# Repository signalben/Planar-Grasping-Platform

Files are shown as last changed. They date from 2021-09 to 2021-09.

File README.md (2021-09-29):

# Planar-Grasping-Platform

<p float="left">
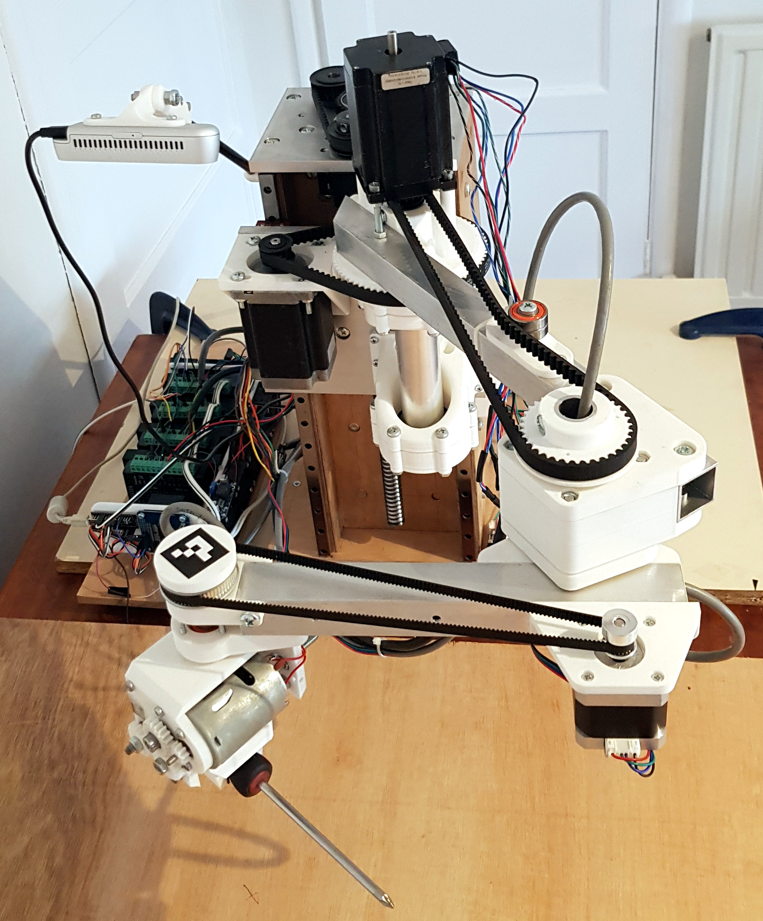
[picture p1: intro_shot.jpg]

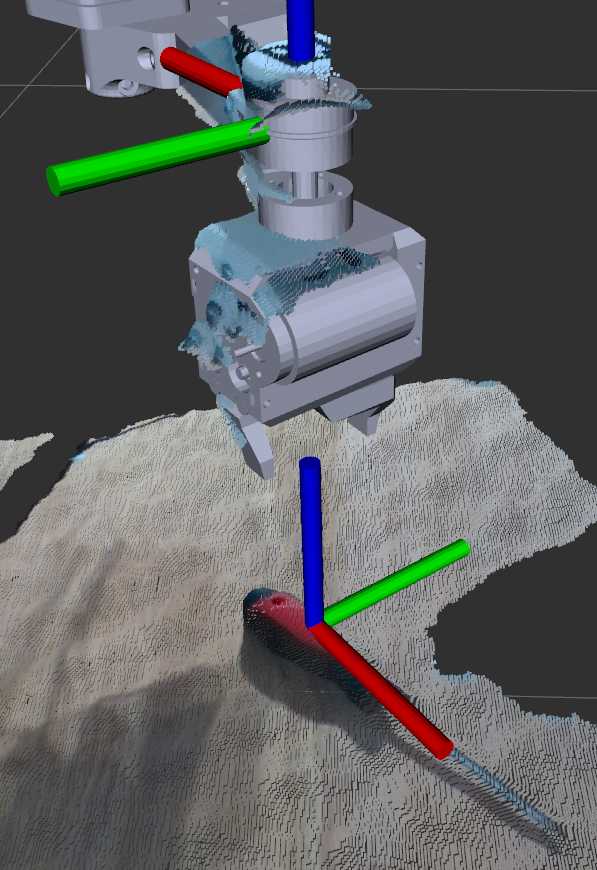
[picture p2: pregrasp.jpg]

</p>

_________________________________________________________________________________
## Demonstration videos

Successful grasps:  
https://youtu.be/Sxl_OcmL-3o  
https://youtu.be/Iijbrh8ghpE  
https://youtu.be/rKQw1soyyW4  

Failed grasps:  
https://youtu.be/VdM2XRzhyX0  
https://youtu.be/__iQ3P3LJT0  
https://youtu.be/dziLtvFLTpc  

Visualizations:  
https://youtu.be/MQvtPGrG9rY  
https://youtu.be/M_flOcwguvU

_________________________________________________________________________________
## Components
scara_CAD 		- Contains models of the scara arm, gripper, mounts for the endstops, camera, microcontrollers  
Arduino_controllers	- Contains the Arduino sketches used for low-level control of the scara arm and gripper  
electrical_schematic	- Details electrical components used and is a full wiring diagram  
scara_ws		- Is the ROS workspace used for high-level control of the arm  
grasp_generation	- Is the implimentation used for generating planar grasps from depth images  
_________________________________________________________________________________
## Prerequisites
Ubuntu   version: 16.04  
ROS    	 version: kinetic
_________________________________________________________________________________
## Running in demo mode
This repository is already configured to run without a physical robot.
However, an Arduino Mega and an Arduino Nano are required.

For use with a real robot, set real_robot = true in the following files:
Arduino_controllers/gripper/gripper.ino  
scara_ws/src/scara_grasping/scripts/execute_grasps.py  
_________________________________________________________________________________
## Setup

Please refer to the installation instructions in the following files:

/Arduino_controllers/README  
/scara_ws/src/README  
/grasp_generation/ggcnn-master/README  
_________________________________________________________________________________
## Running Manipulator
-after Arduino, ROS, CNN installations, connect Nano to "/dev/ttyUSB0"  
-port is specified in ~/scara_ws/src/scara_driver/src/driver.cpp  

-In a new terminal:  
roscore  

-In a new terminal:  
rosrun scara_driver driver  

-In a new terminal:  
rosrun scara_driver user  

-In a new terminal:  
rostopic echo /update/joint_states  

-In the user terminal:  
&E  
-the driver terminal should now print "Enabled control of arm and gripper"    

-In the user terminal:  
 #?  
-the driver terminal prints the status of GRBL  
-this begins with "<alarm|" , indicating that the arm has not been homed and is disabled for safety  
-the /update/joint_states topic should echo one new jointstate, as reported by GRBL status message  

-Either disable the homing requirement by entering in the user terminal:  
 #$X  

-Or home a real manipulator to endstops by instead entering:  
 #$H  

-In the user terminal:  
 #?  
-The GRBL status message should now begin with <Idle|  
-the /update/joint_states topic should echo another jointstate  
 
-In the user terminal:  
run  

-The driver terminal reports "Updating Jointstates from GRBL.."  
-the /update/joint_states topic continuously updates at 10hz  
-the driver node no longer shows status messages  
-updating the jointstates can be disabled by entering 'stop' in the user node  

-In a new terminal:  
rosrun scara_grasping joint_trajectory_action.py  

-In a new terminal:  
roslaunch scara_bringup bringup.launch  
  - If no camera is plugged in, use realsense:=0 argument not to run the camera node   
  - To disable the broadcast of a static transform for the camera use argument camera_pose:=0  

-RVIZ should open, with the scara manipulator and a motionplanning panel shown on screen  
__________________________________________________________________________________
## Veryifying setup

To verify:  
- In the 'MotionPlanning' panel, select 'Planning' -> 'Select Goal State' -> 'ready'  
- Then click 'Update', then 'Plan and Execute'  
- The model should move from the home position to a new pose, it's position is fedback by GRBL  

The arm can also be commanded manually using G-CODE in the user terminal, eg:  
#G0 X-30   (moves XJ 30 deg clockwise)  
&C150      (sets jaw opening width)  
_________________________________________________________________________________
## Grasping  

-In a new terminal:  
roslaunch scara_grasping cnn.launch  

To run the grasping routine-  
In a new terminal:  
rosrun scara_grasping execute_grasps.py  

To only view grasps-  
Close execute_grasps.py, in a new terminal:   
rosrun scara_grasping view_grasps.py  

-The calibration routine will not work without a real robot  
To run the calibration routine for determining the camera pose:    
Close execute_grasps.py, view_grasps.py, bringup.launch   

in a new terminal:   
roslaunch scara_bringup bringup.launch camera_pose:=0   

in a new terminal:  
rosrun scara_grasping calibration.py  
__________________________________________________________________________________
## Debugging    
Should an unresolvable error occur, restart all terminals and roscore.  
This won't lose the manipulators position, the setup commands are listed again below:  

roscore  
rosrun scara_driver driver  
rosrun scara_driver user  
 &E  
 #$X  
 run  
rosrun scara_grasping joint_trajectory_action.py  
roslaunch scara_bringup bringup.launch   

Common errors:  
0 grasps detected   		- Is the RGB-D camera pointed at an object?  
Gripper not in view 		- Is an AruCo marker fully visible in /camera/color/image_rect_color?  
Failed to get grasp from CNN    - roslaunch scara_grasping cnn.launch  

__________________________________________________________________________________

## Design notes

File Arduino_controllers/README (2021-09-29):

This software allows low-level actuation of the scara arm and gripper, controlled over USB serial. 

The gripper controller was developed as part of this work, but includes code references. It runs on an Arduino Nano.
The scara controller is existing software. It runs on an Arduino Mega 2560.

_________________________________________________________________________________
## Installation

Plug in an Arduino Mega, open the Arduino IDE, select tools -> board -> Mega 2560
From the top bar select Sketch -> Include Library -> Add ZIP.library
Navigate to the following folder, click OK:
~/Arduino_controllers/scara_controller/grbl-Mega-4axis-4axis/grbl
Open and upload the sketch:
~/Arduino_controllers/scara_controller/grbl-Mega-4axis-4axis/grbl/examples/grblUpload/grblUpload.ino
To verify the upload, on the serial monitor at 57600 baud, the following message should be recieved:
"Grbl 1.1e ['$' for help]"

Plug in an Arduino Nano, in the Arduino IDE, select tools -> board -> Nano
Open and upload the sketch:
~/Arduino_controllers/gripper/gripper.ino
To verify the upload, on the serial monitor at 57600 baud, the following message should be recieved:
"Ready - Use &E to enable control"

Using jumper leads, link the following pins:
Mega Rx0 to Nano D9
Mega Rx1 to Nano D8 
Mega Gnd to Nano Gnd

For further use only the Nano should be connected via USB

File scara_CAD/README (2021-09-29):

These folders contain the deign for all the mechanical components of the grasping platform.
The Solidworks parts and assemblies are present, but not the STLs used to 3D print them.

The main manipulator with gripper assembly is: 
manipulator/arm.SLDASM

The gripper and camera mounts are the following subassemblies:
gripper/gripper.SLDASM
realsenseD415_mount/realsense_mount.SLDASM

Designs produced to mount the endstop switches, electronics, and to test the grippers force are also included:
/home/ben/Planar-Grasping-Platform/scara_CAD/endstops
/home/ben/Planar-Grasping-Platform/scara_CAD/controller
/home/ben/Planar-Grasping-Platform/scara_CAD/force_sensor_package/load_cell_cone.SLDPRT

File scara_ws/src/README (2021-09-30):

__________________________________________________________________________
## Overview

scara_ws contains packages, folders for operation of the SCARA manipulator and gripper:

serial              - folder contains C++ library to allow USB serial port comms 
scara_driver        - allows ROS control over serial
scara_description   - folder contains URDF and STLs of mechanical design
scara_moveit_config - configuration for control of arm with moveit  
scara_bringup       - runs static camera transform, joint state publisher, robot state publisher, realsense camera, moveit, rviz
scara_grasping      - controller for moveit to control arm. Starts the CNN. Provides routines for grasp execution, grasp visualization and calibration of camera pose

Please note the naming convention of manipulator joints, where:  
J1 = ZJ, J2 = XJ, J3 = YJ, J4 = AJ

References:
Serial library
Website: http://wjwwood.github.io/serial/

All other packages and folders were developed as part of this work, but depend on referenced existing work and code
__________________________________________________________________________
## Installation of ROS

Used following guide to install ROS kinetic:
http://wiki.ros.org/kinetic/Installation/Ubuntu 

This specific installation used: 
sudo apt-get install ros-kinetic-desktop-full
echo "source /opt/ros/kinetic/setup.bash" >> ~/.bashrc
source ~/.bashrc
sudo apt install python-rosdep python-rosinstall python-rosinstall-generator python-wstool build-essential
sudo rosdep init
rosdep update
_________________________________________________________________________________
## Installation of ROS packages

-In a new terminal:
cd Planar-Grasping-Platform/scara_ws/
catkin_make

-Add the fullpath of scara_ws/devel/setup.bash to bashrc:
echo "source /home/"YOUR_USERNAME"/Planar-Grasping-Platform/scara_ws/devel/setup.bash" >> ~/.bashrc
source ~/.bashrc

-In a new terminal:
roscd scara_description
python localize.py

-Install prerequisite packages:

sudo apt-get install ros-kinetic-realsense2-camera
sudo apt install ros-kinetic-rgbd-launch
sudo apt-get install ros-kinetic-moveit

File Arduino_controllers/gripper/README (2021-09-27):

gripper.ino is designed for use on a Arduino Nano.

It has 4 main purposes:
	1-Pass serial communication recieved on port0 (PC) to port1 (Arduino Mega running GRBl)
	2-Pass feedback from GRBl to PC
	3-Control the gripper as specified by PC
	4-Pass feedback from the gripper to PC

Since the Nano has only one hardware serial port, AltSoftSerial is used for port1.

The main loop simply checks port0 and port1 for incoming mesages. Messages from GRBL are forwarded to the PC.
Messages from the PC are either passed to GRBL, or interpreted as a gripper command (depnding on prefix # or &) 
Gripper commands may (depending on prefixes C,D,L,H,S,P)
	E -enable communication with the gripper and arm
	C -control the gripper using PID to a specified position
	D -disable communication with the gripper and arm
	L -report the minimum safe sensor value
	H -report the maximum safe sensor value
	S -report the current sensor value
	P -close the gripper using a constant PWM value

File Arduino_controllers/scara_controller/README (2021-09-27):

GRBL is used for low-level control of the scara arm by an Arduino Mega.
This existing software has not been modified, other than setting configuration parameters

To flash GRBL onto an Arduino Mega2560:
	-in the Arduino IDE, open grbl-Mega-4axis-4axis/grbl/examples/grblUpload.ino
	-compile & upload only grblUpload.ino, it pulls in everything else

Reference:

	https://github.com/dguerizec/grbl-Mega-4axis

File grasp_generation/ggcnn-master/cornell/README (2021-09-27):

The Cornell grasping dataset is over 11gb, so it is not included here.

The original link for downloading the Cornell grasping dataset is dead, but it can be downloaded from:
	https://www.kaggle.com/oneoneliu/cornell-grasp

After downloading, extract into this folder, giving this structure:
	Planar-Grasping-Platform/grasp_generation/ggcnn-master/cornell/samples

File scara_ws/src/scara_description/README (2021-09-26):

The scara description package contains:

-STl files for each link of the scara arm and gripper

-The URDF describing the kinematics scara arm and gripper
	Upon this URDF moveit depends for control of the arm and RVIZ depends for visualization of the STL files.
	The URDF was automatically created by the SolidWorks to URDF Exporter- Originally created by Stephen Brawner (brawner@gmail.com), http://wiki.ros.org/sw_urdf_exporter

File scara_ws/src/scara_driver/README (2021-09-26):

The scara driver package provides an interface between ROS and the controllers for the manipulator and gripper.

The driver node requires a device connected to /dev/ttyUSB0 to run, and will not tolerate disconnection of the device whilst running.
However, the positions of the arm are stored by GRBL, so the driver node may be restarted without losing the position of the arm.

The user node is primarily for debugging/inspection of the microcontrollers via serial.
However, it is required to manually enable and home the arm on startup with '&E' and '#$H'

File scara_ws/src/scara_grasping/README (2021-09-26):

In /scripts, the scara_grasping package provides high-level functionality for:
	executing grasps
	viewing grasps
	calibrating the cameras frame relative to the world

These functionalities depend on scripts in scripts/utils, which provide:
	a link via sockets to the CNN, which also captures depth images (cnn_link.py)
	a controller for MoveIt (joint_trajectory_action.py)
	helper classes for control of the gripper (move_gripper.py)
	helper classes for control using MoveIt (move_group.py)
	helper classes for tf functions (projection.py)
	helper classes for obtaining the grippers position visually, which also captures RGB images (visual_feedback.py)

cnn.launch uses a bash script to start the CNN for generating grasps

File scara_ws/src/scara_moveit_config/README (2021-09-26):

This package contains the configuration and launch files required to control the SCARA arm with the moveit package.
-Do not run/launch any files in this package directly, they are called from scara_bringup bringup.launch.

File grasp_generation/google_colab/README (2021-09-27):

The file lists the Jupiter Cell commands used within Google Colab to train the GGCNN and derivatives of it remotely
Upload is much quicker without orginal .pcd files from Cornell dataset,
Once .tiffs are produced by ggcnn-master/utils/dataset_processing/generate_cornell_depth.py, GGCNN training only uses the much smaller .tiffs

#check that GPU is assigned
	!nvidia-smi

#mount google drive as persistant storage (prompts browser login)
	from google.colab import drive
	drive.mount('/content/gdrive')

#navigate to /root of runtime instance machine
	cd

#make folder for temporary storage local to runtime instance 
	mkdir /content/ggcnn-master

#copy entire dataset, everything else needed for training to runtime instance
#make take 1hr+    
	!cp -r "/content/gdrive/My Drive/ggcnn-master" "/content/ggcnn-master"

#navigate train_ggcnn.py directory
	cd /content/ggcnn-master/ggcnn-master/

#begin training 
#use run after (ctrl F10), so that following commands are executed automatically
#1 epoch = around 4 mins on Tesla V100
	!python3 train_ggcnn.py --description test10 --network ggcnn2 --dataset cornell --dataset-path "cornell" --epochs 100

#navigate to /root
	cd

#copy trained model to google drive
!cp -r "/content/ggcnn-master/ggcnn-master/output" "/content/gdrive/My Drive"

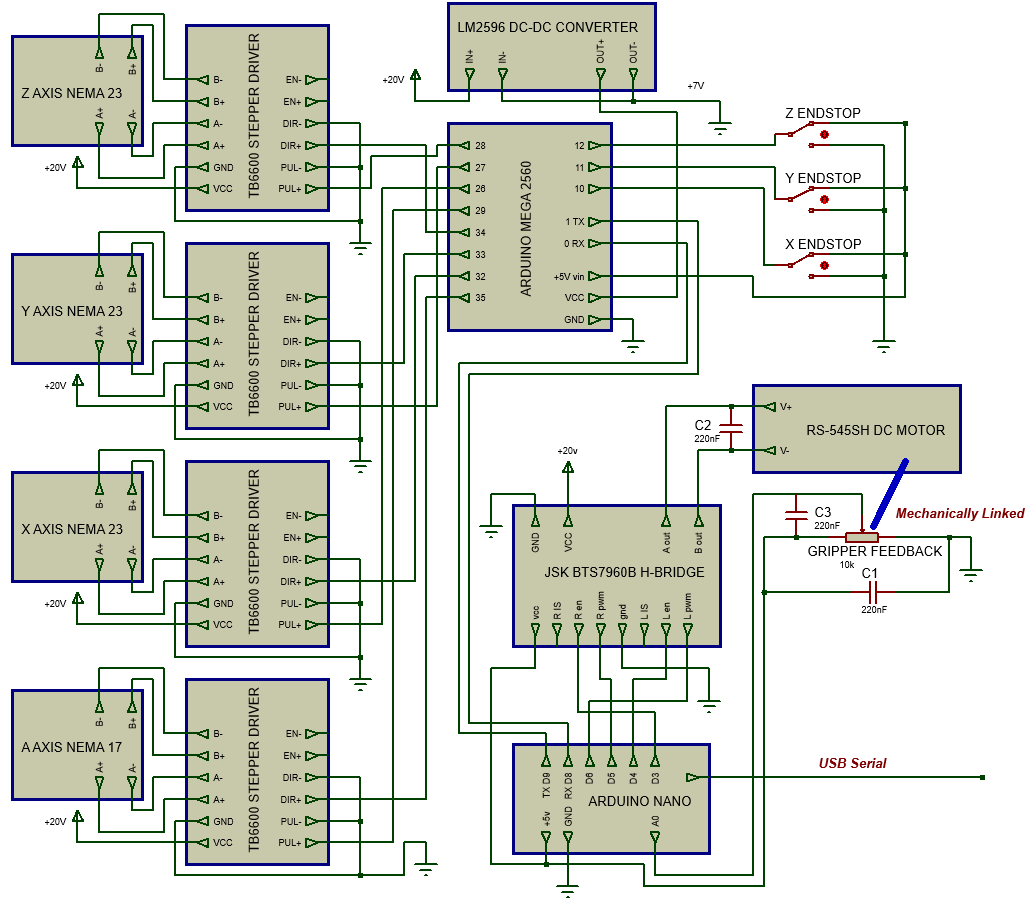
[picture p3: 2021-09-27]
electrical_schematic.png

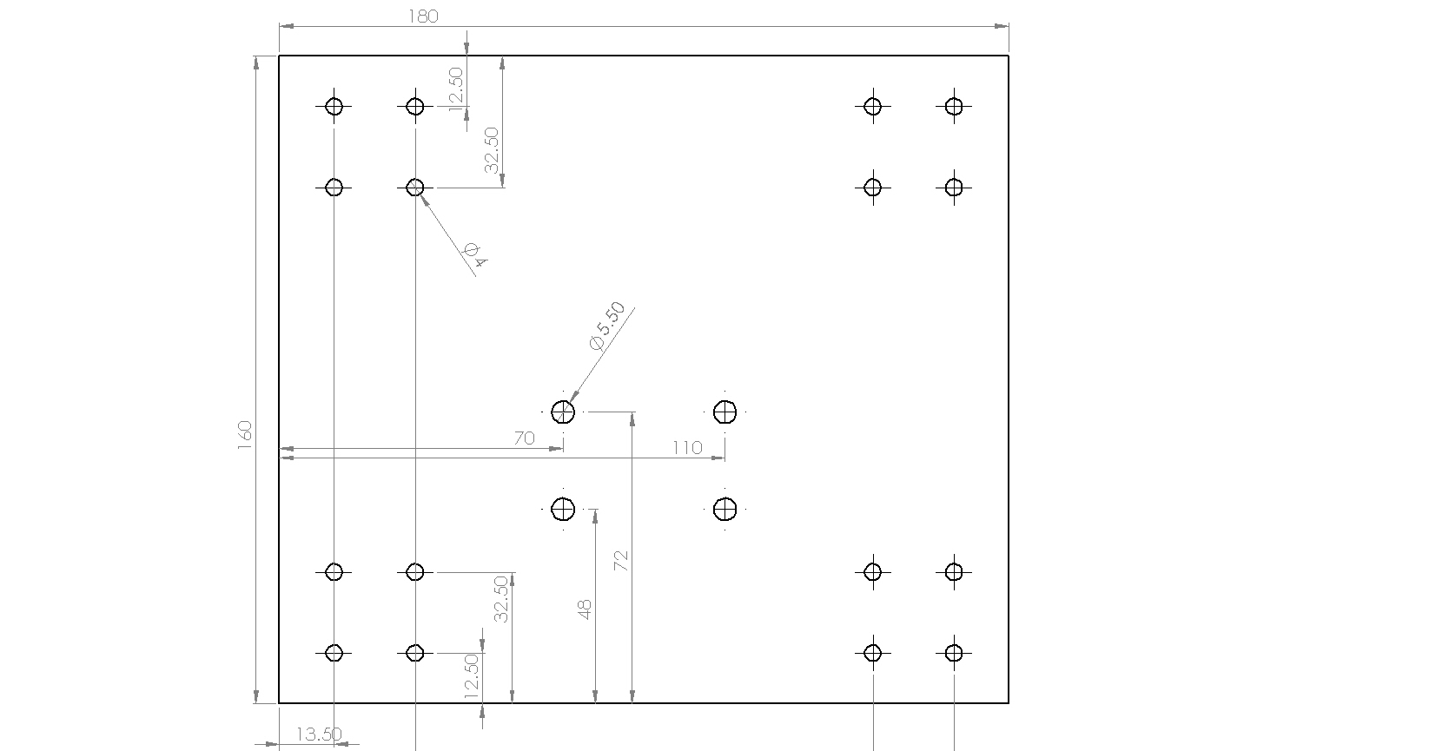
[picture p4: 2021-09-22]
scara_CAD/plate_drawings/mount_plate.JPG

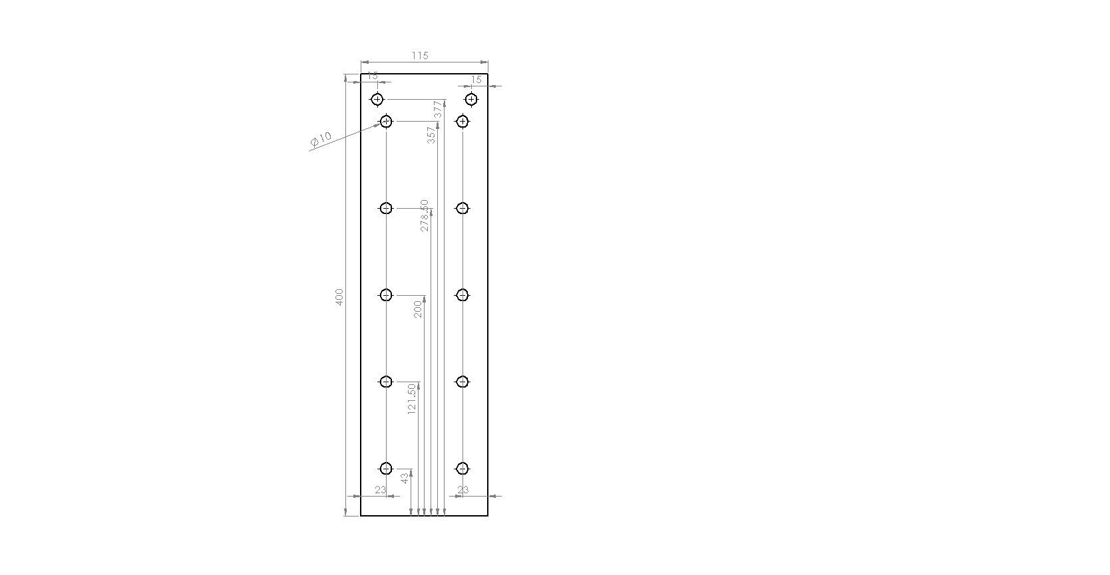
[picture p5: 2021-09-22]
scara_CAD/plate_drawings/back_plate.JPG

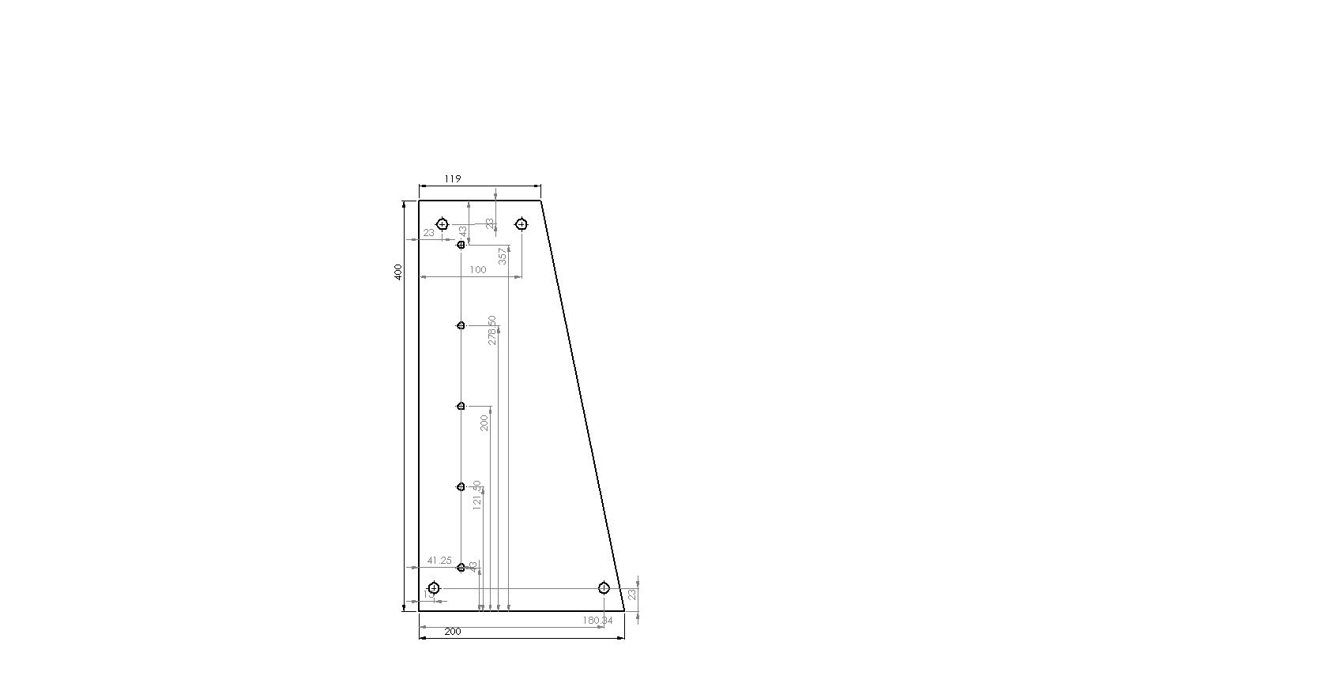
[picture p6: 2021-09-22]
scara_CAD/plate_drawings/side_plate.JPG

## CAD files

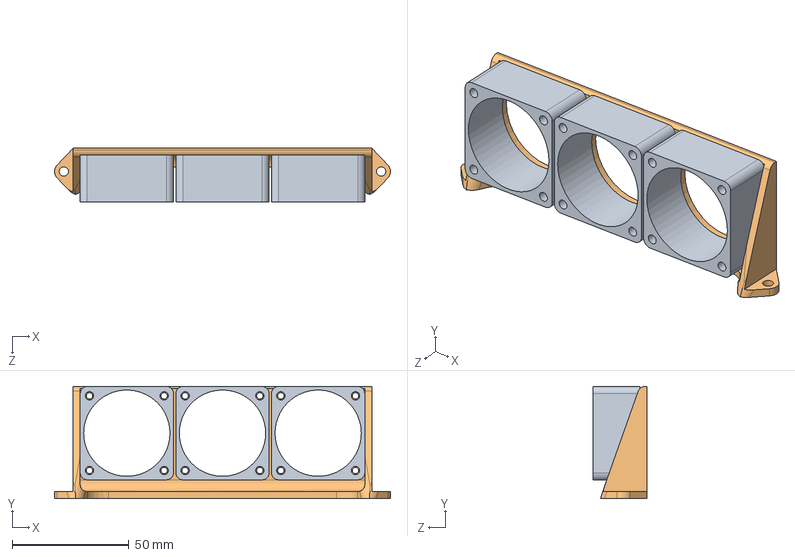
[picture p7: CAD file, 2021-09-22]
scara_CAD/controller/controller.SLDASM
144.0 x 48.0 x 23.0 mm
fan x 3
fan_plate

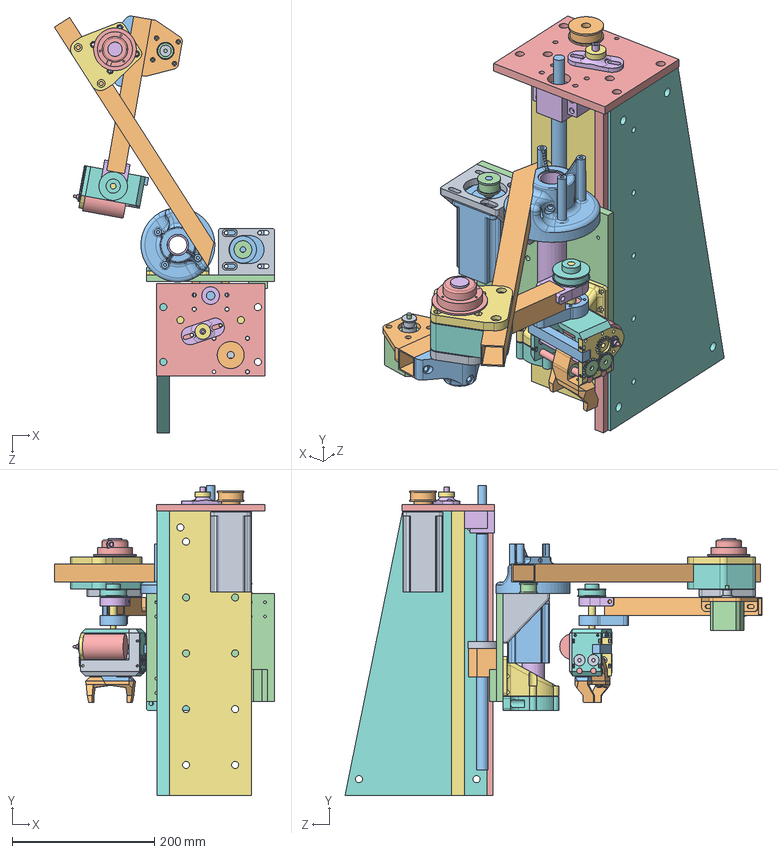
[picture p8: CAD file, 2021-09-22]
scara_CAD/manipulator/link4.SLDASM
309.7 x 436.0 x 586.5 mm
linear_bearing x 2
rod x 2
m6screw x 2
shell_no_motor
bearing6mm x 4
jaw_potentiomer
jaw
gear1 x 2
motor
mgear
igear
top
small_side_plate_motor
finger x 2
potentiomer

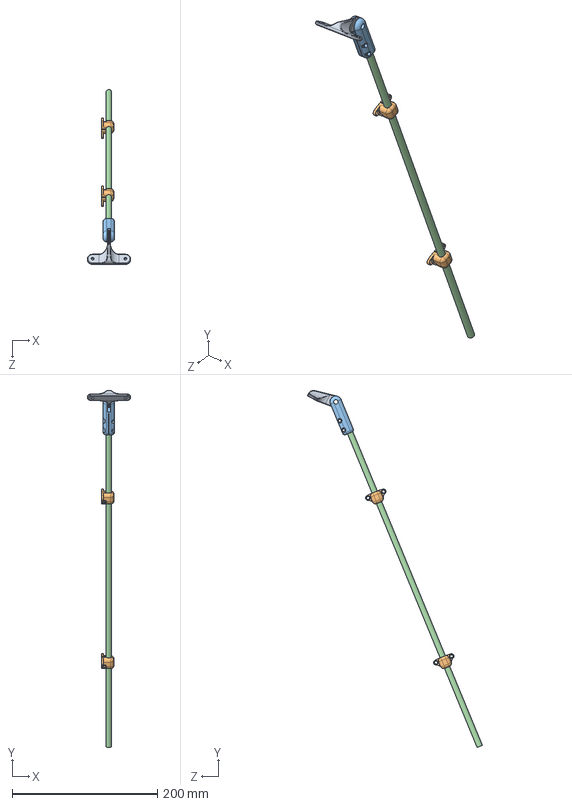
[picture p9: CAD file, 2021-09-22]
scara_CAD/realsenseD415_mount/realsense_mount.SLDASM
59.8 x 491.4 x 240.8 mm
realsense mount
sidemount2 x 2
realsenseend
camera_rod

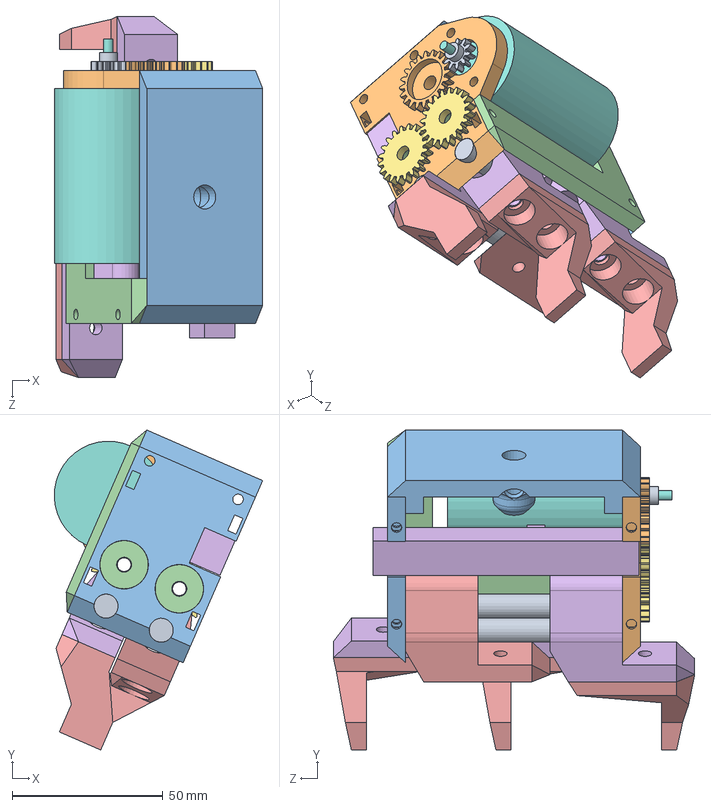
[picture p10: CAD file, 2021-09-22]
scara_CAD/gripper/gripper.SLDASM
69.2 x 106.3 x 120.0 mm
rod x 2
shell_no_motor
bearing6mm x 4
gear1 x 2
motor
mgear
igear
top
small_side_plate_motor
potentiomer
jaw x 2
finger x 2

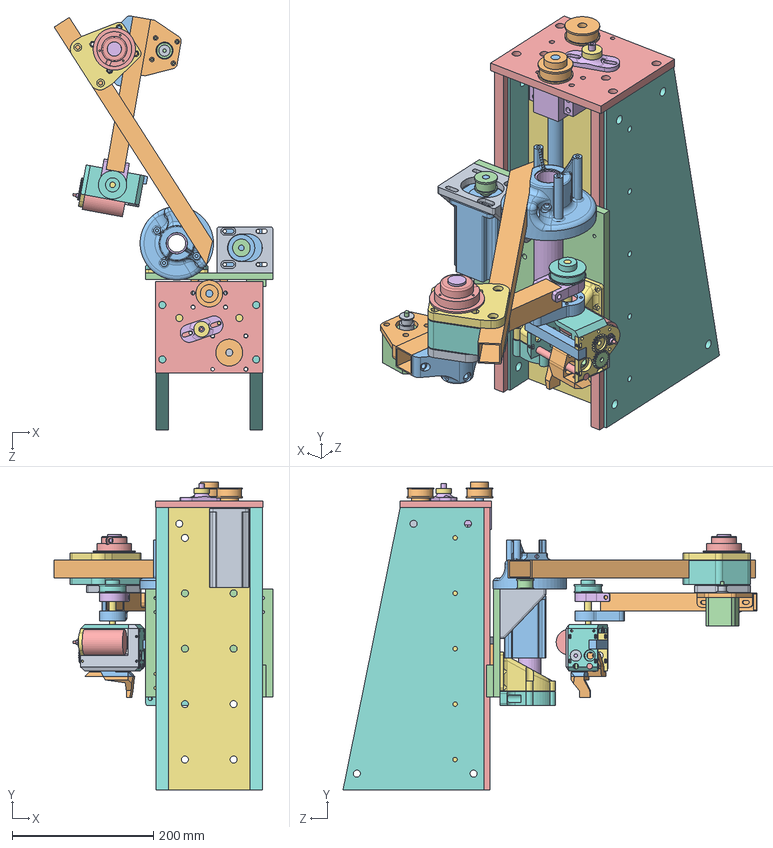
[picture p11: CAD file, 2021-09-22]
scara_CAD/manipulator/link0.SLDASM
309.7 x 436.0 x 586.5 mm
ballscrew
linear_rail x 2
ballscrew_main_bearing
back_plate
side_plate x 2
Copy of nema23_long^arm
Copy of htd-22-15^arm x 2
top_plate2
new_tensioner
skate_bearing2

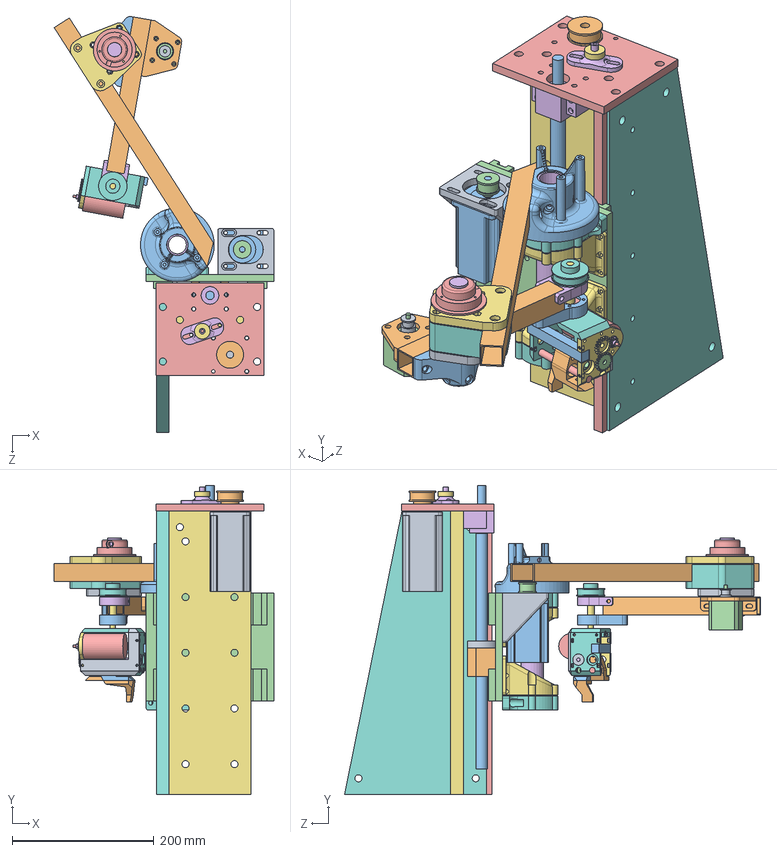
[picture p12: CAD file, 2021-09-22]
scara_CAD/manipulator/link1.SLDASM
309.7 x 436.0 x 586.5 mm
ballnut
ballnut_holder
linear_carriage x 4
nema23_short^link0
htd_14t^link0
large_bearing x 2
buttress x 2
retainer x 2
Copy of motot_mount_1^link0
ally_plate1

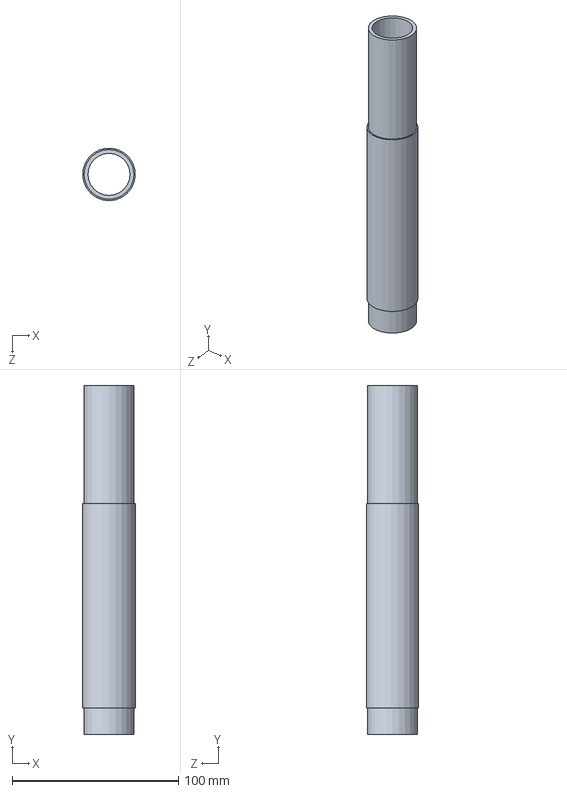
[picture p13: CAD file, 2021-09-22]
scara_CAD/manipulator/mainshaft.SLDPRT
31.6 x 210.0 x 31.6 mm

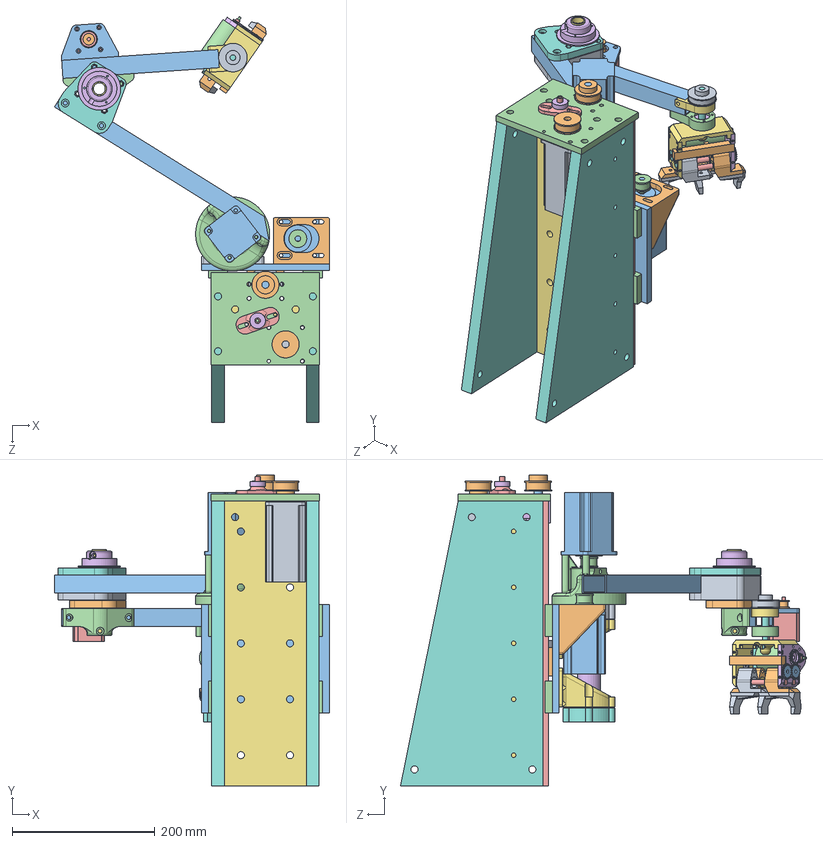
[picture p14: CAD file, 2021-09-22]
scara_CAD/manipulator/arm.SLDASM
386.1 x 436.0 x 569.7 mm
ballnut
ballnut_holder
ballscrew
linear_carriage x 4
linear_rail x 2
ballscrew_main_bearing
back_plate
side_plate x 2
Copy of nema23_long^arm
Copy of htd-22-15^arm x 2
nema23_short^arm x 2
htd_14t^arm x 2
large_bearing x 2
mainshaft
buttress x 2
retainer_basic
retainer
Copy of motot_mount_1^arm
ally_bar
clamp3
medium_bearing x 2
35t_htd^arm
shaft2
Copy of j2_end_clamp^arm
Copy of Copy of j2_end_clamp^arm
Copy (2) of Copy of j2_end_clamp^arm
ally_bar_12
joint2
nema17
skate_bearing x 2
j3top
smallshaft
gt2_60t
gt2_25t
nema17_mount
j3bottomnew
rod x 2
shell_no_motor
bearing6mm x 4
gear1 x 2
motor
mgear
igear
top
small_side_plate_motor
potentiomer
jaw x 2
finger x 2
ally_plate1
top_plate2
new_tensioner
skate_bearing2
linear_bearing x 2

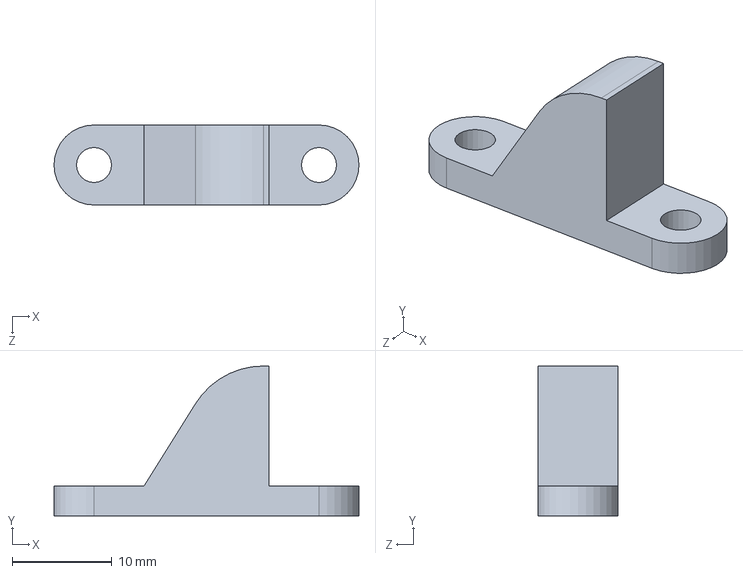
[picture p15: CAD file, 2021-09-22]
scara_CAD/endstops/z_trigger.SLDPRT
30.5 x 15.0 x 8.00 mm

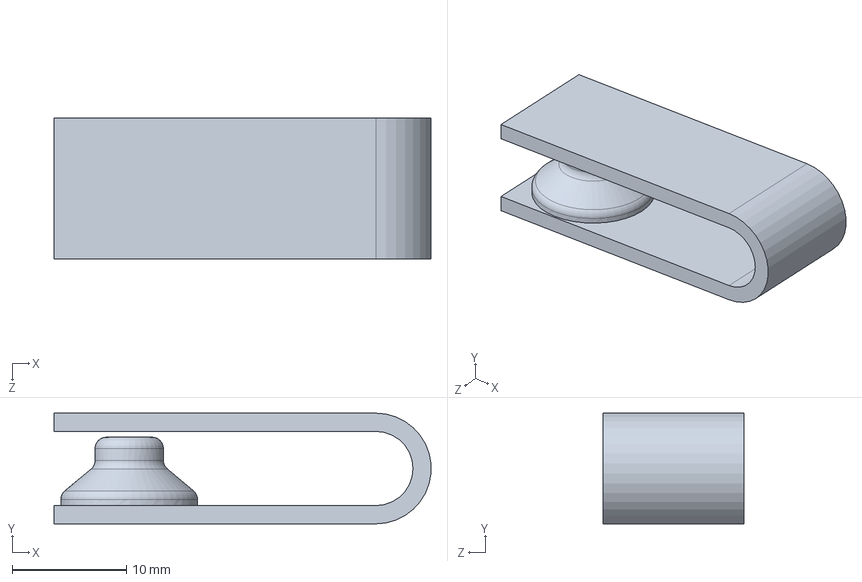
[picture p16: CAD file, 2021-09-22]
scara_CAD/force_sensor_package/load_cell_cone.SLDPRT
33.0 x 9.70 x 12.3 mm

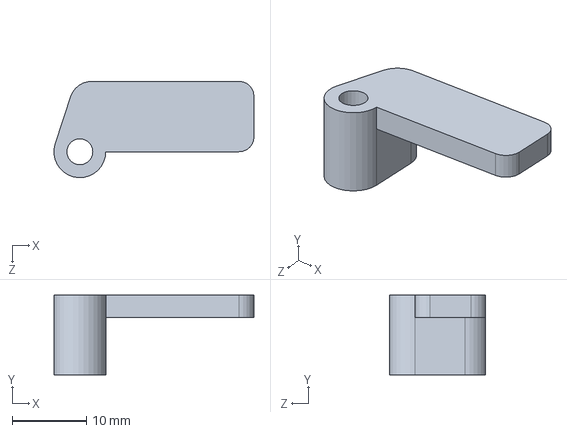
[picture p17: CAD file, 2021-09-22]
scara_CAD/gripper/drv_riser.SLDPRT
27.0 x 10.8 x 13.0 mm

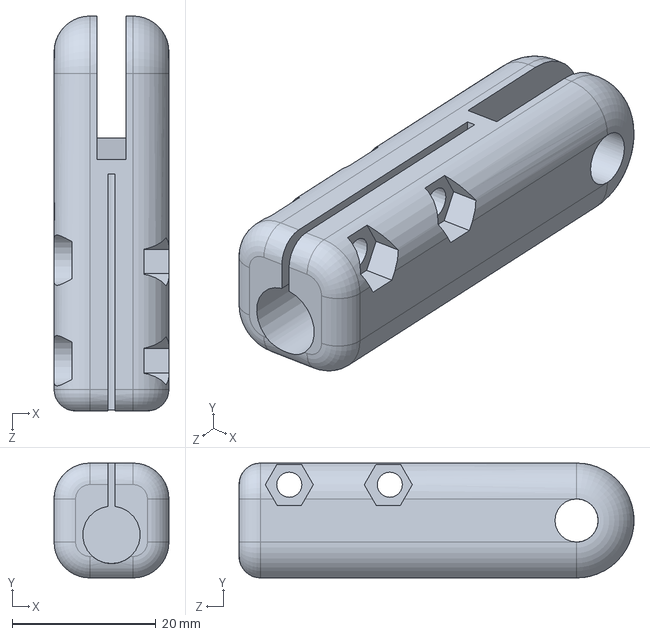
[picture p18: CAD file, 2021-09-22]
scara_CAD/realsenseD415_mount/realsenseend.SLDPRT
16.0 x 16.0 x 55.0 mm

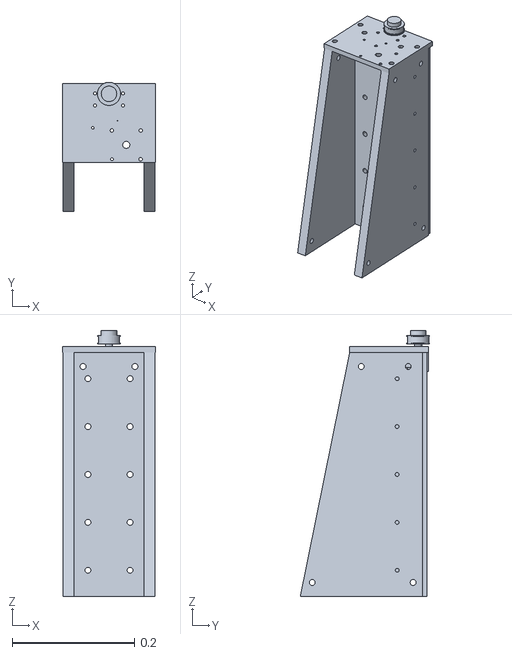
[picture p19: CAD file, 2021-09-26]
scara_ws/src/scara_description/base_link.STL
0.152 x 0.212 x 0.436

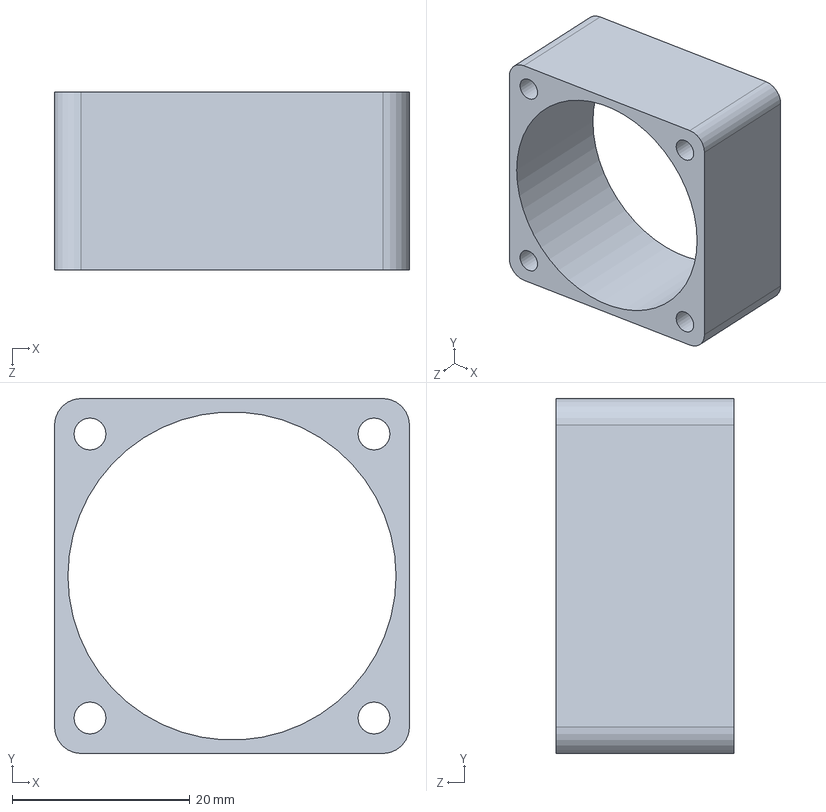
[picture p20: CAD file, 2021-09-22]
scara_CAD/controller/fan.SLDPRT
40.0 x 40.0 x 20.0 mm

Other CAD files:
scara_CAD/manipulator/link2.SLDASM
scara_CAD/manipulator/link3.SLDASM
scara_CAD/manipulator/Belt1.SLDPRT
scara_CAD/endstops/amount.SLDPRT
scara_CAD/controller/clamp.SLDPRT
scara_CAD/controller/fan_plate.SLDPRT
scara_CAD/controller/mega holder.SLDPRT
scara_CAD/controller/nano holder.SLDPRT
scara_CAD/endstops/amount2.SLDPRT
scara_CAD/endstops/bmount.SLDPRT
scara_CAD/endstops/zmount#.SLDPRT
scara_CAD/gripper/bearing6mm.SLDPRT
scara_CAD/gripper/finger.SLDPRT
scara_CAD/gripper/gear1.SLDPRT
scara_CAD/gripper/igear.SLDPRT
scara_CAD/gripper/jaw.SLDPRT
scara_CAD/gripper/jaw_potentiomer.SLDPRT
scara_CAD/gripper/linear_bearing.SLDPRT
scara_CAD/gripper/mgear.SLDPRT
scara_CAD/gripper/mini_bearing.SLDPRT
scara_CAD/gripper/motor.SLDPRT
scara_CAD/gripper/potentiomer.SLDPRT
scara_CAD/gripper/rod.SLDPRT
scara_CAD/gripper/shell.SLDPRT
scara_CAD/gripper/shell_no_motor.SLDPRT
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

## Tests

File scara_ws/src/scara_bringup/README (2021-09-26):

bringup.launch is responable for:
loading the parameters needed to start moveit
starting a static transform publisher for the camera links pose
starting a joint state publisher to allow other nodes asyncronous access to joint states
starting a robot state publisher to give tf frames for each link based on the joint states
launching the realsense camera node (unless realsense:= 0 is given as an argument)
launching scara.launch (which in turn launches moveit and RVIZ)

Moveit will be unable to control the arm if the following nodes are not already running before launching bringup.launch:
rosrun scara_driver driver
rosrun scara_grasping joint_trajectory_action.py

The following must then be run to view/execute grasps: 
roslaunch scara_grasping cnn.launch
rosrun scara_grasping execute_grasps.py or rosrun scara_grasping view_grasps.py

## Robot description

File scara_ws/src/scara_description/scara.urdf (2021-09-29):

<?xml version="1.0" encoding="utf-8"?>
<!-- This URDF was automatically created by SolidWorks to URDF Exporter! Originally created by Stephen Brawner (brawner@gmail.com) 
     Commit Version: 1.6.0-1-g15f4949  Build Version: 1.6.7594.29634
     For more information, please see http://wiki.ros.org/sw_urdf_exporter 
	https://answers.ros.org/question/243910/easily-move-relative-base-position-in-urdf-for-2-seperate-robots/-->

<robot name="scara">

  <link name="world" />

  <link name="base_link">
    <visual>
      <origin xyz="0 0 0" rpy="0 0 0" />
      <geometry>
        <mesh filename="file://PLACEHOLDER/base_link.STL" /> 
      </geometry>
      <material name="">
        <color rgba="0.792156862745098 0.819607843137255 0.933333333333333 1" />
      </material>
    </visual>
    <collision>
      <origin xyz="0 0 0" rpy="0 0 0" />
      <geometry>
        <mesh filename="file://PLACEHOLDER/base_link.STL" />
      </geometry>
    </collision>
  </link>

  <joint name="offset" type="fixed">
    <origin xyz="0.1 0.1 -0.12" rpy="0 0 0" />
    <parent link="world" />
    <child link="base_link" />
    <axis xyz="0 1 0" />
  </joint>

  <link name="ZL">
    <visual>
      <origin xyz="0 0 0" rpy="0 0 0" />
      <geometry>
        <mesh filename="file://PLACEHOLDER/ZL.STL" />
      </geometry>
      <material name="">
        <color rgba="0.792156862745098 0.819607843137255 0.933333333333333 1" />
      </material>
    </visual>
    <collision>
      <origin xyz="0 0 0" rpy="0 0 0" />
      <geometry>
        <mesh filename="file://PLACEHOLDER/ZL.STL" />
      </geometry>
    </collision>
  </link>

  <joint name="ZJ" type="prismatic">
    <origin xyz="-0.10866 -0.075122 0.19155" rpy="1.5708 0 0" />
    <parent link="base_link" />
    <child link="ZL" />
    <axis xyz="0 1 0" />
<limit effort="1000.0" lower="0" upper="0.22" velocity="1"/>
  </joint>

  <link name="XL">
    <visual>
      <origin xyz="0 0 0" rpy="0 0 0" />
      <geometry>
        <mesh filename="file://PLACEHOLDER/XL.STL" />
      </geometry>
      <material name="">
        <color rgba="0.792156862745098 0.819607843137255 0.933333333333333 1" />
      </material>
    </visual>
    <collision>
      <origin xyz="0 0 0" rpy="0 0 0" />
      <geometry>
        <mesh filename="file://PLACEHOLDER/XL.STL" />
      </geometry>
    </collision>
  </link>

  <joint name="XJ" type="revolute">
    <origin xyz="-0.045996 0 -0.042" rpy="3.1416 -0.065872 3.1416" />
    <parent link="ZL" />
    <child link="XL" />
    <axis xyz="0 1 0" />
   <limit effort="1000.0" lower="-4.5" upper="0" velocity="1"/>
  </joint>

  <link name="YL">
    <visual>
      <origin xyz="0 0 0" rpy="0 0 0" />
      <geometry>
        <mesh filename="file://PLACEHOLDER/YL.STL" />
      </geometry>
      <material name="">
        <color rgba="0.792156862745098 0.819607843137255 0.933333333333333 1" />
      </material>
    </visual>
    <collision>
      <origin xyz="0 0 0" rpy="0 0 0" />
      <geometry>
        <mesh filename="file://PLACEHOLDER/YL.STL" />
      </geometry>
    </collision>
  </link>

  <joint name="YJ" type="revolute">
    <origin xyz="0.17822 0.0243 -0.21159" rpy="-1.5708 -0.72393 0" />
    <parent link="XL" />
    <child link="YL" />
    <axis xyz="0 0 1" />
<limit effort="1000.0" lower="-4.5" upper="1.5" velocity="1"/>
  </joint>

  <link name="AL">
    <visual>
      <origin xyz="0 0 0" rpy="0 0 -2.6335" />
      <geometry>
        <mesh filename="file://PLACEHOLDER/AL.STL" />
      </geometry>
      <material name="">
        <color rgba="0.792156862745098 0.819607843137255 0.933333333333333 1" />
      </material>
    </visual>
    <collision>
      <origin xyz="0 0 0" rpy="0 0 -2.6335" />
      <geometry>
        <mesh filename="file://PLACEHOLDER/AL.STL" />
      </geometry>
    </collision>
  </link>

  <joint name="AJ" type="revolute">
    <origin xyz="-0.18889 -0.036901 0.0473" rpy="0 0 0" />
    <parent link="YL" />
    <child link="AL" />
    <axis xyz="0 0 1" />
 <limit effort="1000.0" lower="-2.5" upper="2.5" velocity="1"/>
  </joint>

  <link name="jaw0">
    <visual>
      <origin xyz="0 0 0" rpy="0 0 0" />
      <geometry>
        <mesh filename="file://PLACEHOLDER/jaw0.STL" />
      </geometry>
      <material name="">
        <color rgba="0.792156862745098 0.819607843137255 0.933333333333333 1" />
      </material>
    </visual>
    <collision>
      <origin xyz="0 0 0" rpy="0 0 0" />
      <geometry>
        <mesh filename="file://PLACEHOLDER/jaw0.STL" />
      </geometry>
    </collision>
  </link>

  <joint name="G0" type="prismatic">
    <origin xyz="0 0 -0.0844" rpy="3.1416 0 0" />
    <parent link="AL" />
    <child link="jaw0" />
    <axis xyz="0 1 0" />
 <limit effort="1000.0" lower="0" upper="0.05" velocity="1000"/>
</joint>

  <link name="jaw1">
    <visual>
      <origin xyz="0 0 0" rpy="0 0 0" />
      <geometry>
        <mesh filename="file://PLACEHOLDER/jaw1.STL" />
      </geometry>
      <material name="">
        <color rgba="0.792156862745098 0.819607843137255 0.933333333333333 1" />
      </material>
    </visual>
    <collision>
      <origin xyz="0 0 0" rpy="0 0 0" />
      <geometry>
        <mesh filename="file://PLACEHOLDER/jaw1.STL" />
      </geometry>
    </collision>
  </link>

  <joint name="G1" type="prismatic">
    <origin xyz="0 0 -0.0844" rpy="-3.1416 0 -1.5708" />
    <parent link="AL" />
    <child link="jaw1" />
    <axis xyz="-1 0 0" />
 <limit effort="1000.0" lower="0" upper="0.05" velocity="1000"/>
  </joint>
</robot>

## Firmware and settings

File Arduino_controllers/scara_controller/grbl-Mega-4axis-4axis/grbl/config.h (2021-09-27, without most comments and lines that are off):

#define config_h
#include "grbl.h" // For Arduino IDE compatibility.
#define DEFAULTS_GENERIC
#define DEFAULTS_ABC_AXIS
#define CPU_MAP_2560_INITIAL
#define BAUD_RATE 57600
#define CMD_RESET 0x18 // ctrl-x.
#define CMD_STATUS_REPORT '?'
#define CMD_CYCLE_START '~'
#define CMD_FEED_HOLD '!'
#define CMD_SAFETY_DOOR 0x84
#define CMD_JOG_CANCEL  0x85
#define CMD_DEBUG_REPORT 0x86 // Only when DEBUG enabled, sends debug report in '{}' braces.
#define CMD_FEED_OVR_RESET 0x90         // Restores feed override value to 100%.
#define CMD_FEED_OVR_COARSE_PLUS 0x91
#define CMD_FEED_OVR_COARSE_MINUS 0x92
#define CMD_FEED_OVR_FINE_PLUS  0x93
#define CMD_FEED_OVR_FINE_MINUS  0x94
#define CMD_RAPID_OVR_RESET 0x95        // Restores rapid override value to 100%.
#define CMD_RAPID_OVR_MEDIUM 0x96
#define CMD_RAPID_OVR_LOW 0x97
#define CMD_SPINDLE_OVR_RESET 0x99      // Restores spindle override value to 100%.
#define CMD_SPINDLE_OVR_COARSE_PLUS 0x9A
#define CMD_SPINDLE_OVR_COARSE_MINUS 0x9B
#define CMD_SPINDLE_OVR_FINE_PLUS 0x9C
#define CMD_SPINDLE_OVR_FINE_MINUS 0x9D
#define CMD_SPINDLE_OVR_STOP 0x9E
#define CMD_COOLANT_FLOOD_OVR_TOGGLE 0xA0
#define CMD_COOLANT_MIST_OVR_TOGGLE 0xA1
#define HOMING_INIT_LOCK // Comment to disable
#define HOMING_CYCLE_0 (1<<Z_AXIS)                // REQUIRED: First move Z to clear workspace.
#define HOMING_CYCLE_1 (1<<X_AXIS)  // OPTIONAL: Then move X,Y at the same time.
#define HOMING_CYCLE_2 (1<<Y_AXIS)  // OPTIONAL: Then move X,Y at the same time.
#define N_HOMING_LOCATE_CYCLE 3 // Integer (1-128)
 #define HOMING_SINGLE_AXIS_COMMANDS // Default disabled. Uncomment to enable.
#define N_STARTUP_LINE 2 // Integer (1-2)
#define N_DECIMAL_COORDVALUE_INCH 4 // Coordinate or position value in inches
#define N_DECIMAL_COORDVALUE_MM   3 // Coordinate or position value in mm
#define N_DECIMAL_RATEVALUE_INCH  1 // Rate or velocity value in in/min
#define N_DECIMAL_RATEVALUE_MM    0 // Rate or velocity value in mm/min
#define N_DECIMAL_SETTINGVALUE    3 // Decimals for floating point setting values
#define N_DECIMAL_RPMVALUE        0 // RPM value in rotations per min.
#define MESSAGE_PROBE_COORDINATES // Enabled by default. Comment to disable.
#define SAFETY_DOOR_SPINDLE_DELAY 4.0 // Float (seconds)
#define SAFETY_DOOR_COOLANT_DELAY 1.0 // Float (seconds)
#define CHECK_LIMITS_AT_INIT
#define DEFAULT_FEED_OVERRIDE           100 // 100%. Don't change this value.
#define MAX_FEED_RATE_OVERRIDE          200 // Percent of programmed feed rate (100-255). Usually 120% or 200%
#define MIN_FEED_RATE_OVERRIDE           10 // Percent of programmed feed rate (1-100). Usually 50% or 1%
#define FEED_OVERRIDE_COARSE_INCREMENT   10 // (1-99). Usually 10%.
#define FEED_OVERRIDE_FINE_INCREMENT      1 // (1-99). Usually 1%.
#define DEFAULT_RAPID_OVERRIDE  100 // 100%. Don't change this value.
#define RAPID_OVERRIDE_MEDIUM    50 // Percent of rapid (1-99). Usually 50%.
#define RAPID_OVERRIDE_LOW       25 // Percent of rapid (1-99). Usually 25%.
#define DEFAULT_SPINDLE_SPEED_OVERRIDE    100 // 100%. Don't change this value.
#define MAX_SPINDLE_SPEED_OVERRIDE        200 // Percent of programmed spindle speed (100-255). Usually 200%.
#define MIN_SPINDLE_SPEED_OVERRIDE         10 // Percent of programmed spindle speed (1-100). Usually 10%.
#define SPINDLE_OVERRIDE_COARSE_INCREMENT  10 // (1-99). Usually 10%.
#define SPINDLE_OVERRIDE_FINE_INCREMENT     1 // (1-99). Usually 1%.
#define RESTORE_OVERRIDES_AFTER_PROGRAM_END // Default enabled. Comment to disable.
#define REPORT_FIELD_BUFFER_STATE // Default enabled. Comment to disable.
#define REPORT_FIELD_PIN_STATE // Default enabled. Comment to disable.
#define REPORT_FIELD_CURRENT_FEED_SPEED // Default enabled. Comment to disable.
#define REPORT_FIELD_WORK_COORD_OFFSET // Default enabled. Comment to disable.
#define REPORT_FIELD_OVERRIDES // Default enabled. Comment to disable.
#define REPORT_FIELD_LINE_NUMBERS // Default enabled. Comment to disable.
#define REPORT_OVR_REFRESH_BUSY_COUNT 20  // (1-255)
#define REPORT_OVR_REFRESH_IDLE_COUNT 10  // (1-255) Must be less than or equal to the busy count
#define REPORT_WCO_REFRESH_BUSY_COUNT 30  // (2-255)
#define REPORT_WCO_REFRESH_IDLE_COUNT 10  // (2-255) Must be less than or equal to the busy count
#define ACCELERATION_TICKS_PER_SECOND 100
#define ADAPTIVE_MULTI_AXIS_STEP_SMOOTHING  // Default enabled. Comment to disable.
#define TOOL_LENGTH_OFFSET_AXIS Z_AXIS // Default z-axis. Valid values are X_AXIS, Y_AXIS, or Z_AXIS.
#define MINIMUM_JUNCTION_SPEED 0.0 // (mm/min)
#define MINIMUM_FEED_RATE 1.0 // (mm/min)
#define N_ARC_CORRECTION 12 // Integer (1-255)
#define ARC_ANGULAR_TRAVEL_EPSILON 5E-7 // Float (radians)
#define DWELL_TIME_STEP 50 // Integer (1-255) (milliseconds)
#define ENABLE_RESTORE_EEPROM_WIPE_ALL         // '$RST=*' Default enabled. Comment to disable.
#define ENABLE_RESTORE_EEPROM_DEFAULT_SETTINGS // '$RST=$' Default enabled. Comment to disable.
#define ENABLE_RESTORE_EEPROM_CLEAR_PARAMETERS // '$RST=#' Default enabled. Comment to disable.
#define ENABLE_BUILD_INFO_WRITE_COMMAND // '$I=' Default enabled. Comment to disable.
#define FORCE_BUFFER_SYNC_DURING_EEPROM_WRITE // Default enabled. Comment to disable.
#define FORCE_BUFFER_SYNC_DURING_WCO_CHANGE // Default enabled. Comment to disable.
#define PARKING_AXIS Z_AXIS // Define which axis that performs the parking motion
#define PARKING_TARGET -5.0 // Parking axis target. In mm, as machine coordinate [-max_travel,0].
#define PARKING_RATE 500.0 // Parking fast rate after pull-out in mm/min.
#define PARKING_PULLOUT_RATE 100.0 // Pull-out/plunge slow feed rate in mm/min.
#define PARKING_PULLOUT_INCREMENT 5.0 // Spindle pull-out and plunge distance in mm. Incremental distance.
#define SLEEP_DURATION 5.0 // Float (0.25 - 61.0) seconds before sleep mode is executed.
#define DISABLE_LASER_DURING_HOLD // Default enabled. Comment to disable.

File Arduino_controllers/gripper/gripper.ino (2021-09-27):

#include <AltSoftSerial.h>

bool enable = false; //control of arm and gripper disabled on startup
AltSoftSerial Serial1; //additionial serial port
int limit = 100; //max PWM value (0-255)
int sensor; //current potentiometer value (0-1023)
float Pg = 20, Ig = 0.025, Dg = 130;// PID gains
//Variables keep recieved target velocities, positional error, current velocities, and previous velocity error (needed to calculate change of velocity error)
float target = 0, PosE = 0, OldVelE = 0, Vel = 0, OldSensor;

//max, min sensor values allowed, prevents damage by attempting to reach outside the travel of the jaws
int maxreach = 855;
int minreach = 85;
float rolling_read;

//Returns analogue position using two separate wires and rolling average filter 
int filtered_read() {
  float new_read = (analogRead(A0) + analogRead(A1)) / 2;
  rolling_read = (0.9 * rolling_read) + (0.1 * new_read);
  return int(rolling_read);
}

//Sets PWM output, limited to prevent damage to gears, overheating of wires
void set_speed(int input) {
  int speed = input;
  if (speed > limit) {
    speed = limit;
  }
  if (speed < -limit) {
    speed = -limit;
  }
  if (speed < 0) {
    digitalWrite(3, HIGH);
    digitalWrite(4, HIGH);
    speed = -speed;
    analogWrite(5, 0);
    analogWrite(6, speed);
  }
  else {
    digitalWrite(4, HIGH);
    digitalWrite(3, HIGH);
    analogWrite(6, 0);
    analogWrite(5, speed);
  }
}

//setup, starts rolling average read of jaw position sensor
void setup() {
  pinMode(3, OUTPUT);
  pinMode(4, OUTPUT);
  pinMode(5, OUTPUT);
  pinMode(6, OUTPUT);
  digitalWrite(3, LOW);
  digitalWrite(4, LOW);
  digitalWrite(5, LOW);
  digitalWrite(6, LOW);
  Serial.begin(57600);
  Serial1.begin(57600);
  set_speed(0);
  rolling_read = (analogRead(A0) + analogRead(A1)) / 2;
  sensor = filtered_read();
  Serial.println("Ready - Use &E to enable control");
}

//Produces target velocities based on positional error
float planner(int error) {

  if (error == 0) {
    Serial.println("&T"); //Gripper target reached
    return 0;
  }

  float setspeed = 7;

  if (abs(error) < 60) {
    setspeed = 1 + ((abs(error)) / 10);
  }
  if (error > 0) {
    return setspeed;
  }
  if (error < 0) {
    return -setspeed;
  }
  Serial.println("Gripper planner error");
  return 0;
}

//empties everything in serial buffer
void  clear_serial_buffer() {
  while (Serial.available() > 0) {
    char junk = Serial.read();
  }
}

//Determines type of gripper command
void read_gripper_msg() {
  char inByte = Serial.read();
  if (inByte == 'C') {
    control_gripper();
  }
  else {
    if (inByte == 'D') {
      Serial.println("Disabled control of arm and gripper");
      enable = false;
    }
    else if (inByte == 'L') {
      Serial.print("Gripper value offset: ");
      Serial.println(minreach);
    }
    else if (inByte == 'H') {
      Serial.print("Maximum gripper value: ");
      Serial.println(maxreach - minreach);
    }
    else if (inByte == 'S') {
      Serial.print("&S"); //Current gripper value 
      Serial.println(sensor - minreach);
    }
    else if (inByte == 'P') {
      Serial.println("Direct PWM");
      direct_pwm();
    }
    clear_serial_buffer();
  }
}

//Intrpret bytes as digits of integer
int get_int() {
  int uPos = 0;
  while (Serial.available() > 0 ) {
    delay(1);
    char inByte = Serial.read();
    int capnum = int(inByte) - 48; //acsi code offet to 0-9

    if ((capnum < 10) && (capnum > -1)) { //if digit is 0-90
      if (uPos == 0) { //first digit so far
        uPos = capnum;
      }
      else {
        uPos =  (uPos * 10) + capnum; //previous digits x10 + next digit
      }
    }
    else {
      break; //no more valid digits return int
    }
  }
  return uPos;
}

//Function closes gripper jaws using recieved PWM value 
void direct_pwm() {
  int pwm_val = get_int();
  set_speed(-pwm_val);
  sensor = filtered_read(); //current position
  int previous = sensor;
  int jammed = 0;
  int jamtime = 20;
  Serial.print("&S"); //Current gripper value 
  Serial.println(sensor - minreach);
  delay(100);

  //enter direct pwm control loop
  while (true) {
    sensor = filtered_read(); //current position

    if (sensor == previous) {
      jammed++;
    }

    if (jammed > jamtime) {
      if (sensor < minreach) {
        Serial.println("&F"); //closure failed
        set_speed(100);
        while (filtered_read() < minreach) {
          delay(1);
        }
        set_speed(0);
        break;
      }
      Serial.println("&C"); //closure sucessfull
      set_speed(0);
      break;
    }
    previous = sensor;
    delay(10);
  }
  delay(100);
  Serial.print("&S"); //Current gripper value 
  Serial.println(sensor - minreach);
}

//Function positions gripper jaws to recieved value using PID
void control_gripper() {

  int uPos = get_int();
  Serial.print("Recieved: ");
  Serial.println(uPos);

  //target position is user specified number above minimum
  int tPos = uPos + minreach;

  //prevent specification of dangerously high target
  if ((tPos > maxreach) || (tPos < minreach)) {
    Serial.print("&F Gripper target out of bounds: ");
    Serial.println(uPos);
    set_speed(0);
  }

  //target accepted
  else {
    Serial.print("&S"); //Current gripper value 
    Serial.println(sensor - minreach);
    delay(100);

    //enter main control loop
    while (true) {
      sensor = filtered_read(); //current position
      int error = (tPos - sensor); //positional error
      target = planner(error); //velocity target

      //break if target reached
      if (target == 0) {
        set_speed(0);
        break;
      }

      //emergancy disable motor if bounds exceeded
      if ((sensor > maxreach) || (sensor < minreach)) {
        Serial.print("Gripper out of bounds: ");
        Serial.println(sensor - minreach);
        while (1) {
          set_speed(0);
        }
      }
      
      //use PID control to set PWM speed
      Vel = sensor - OldSensor;
      float VelE = target - Vel; //proportional error
      PosE += VelE; //update integral/positional error
      PosE = constrain(PosE, -1024, 1024); //prevent too much integral windup
      float AccE = VelE - OldVelE; //derivative/acceleration error
      float output = ((Pg * VelE) + (Ig * PosE) + (Dg * AccE)); //Sum errors, weighted by their gains, scale down to 8 bit range
      set_speed(lround(output));
      delay(10);
      OldVelE = VelE; //Store for use in next call
      OldSensor = sensor;
    }
      delay(100);
      Serial.print("&S"); //Current gripper value 
      Serial.println(sensor - minreach);
  }
}

//functions forward messages between arm and pc
void pass_to_scara() {
  while (Serial.available() > 0) {
    delay(2);
    Serial1.write(Serial.read());
  }
}

void pass_from_scara() {
  while (Serial1.available() > 0) {
    Serial.write(Serial1.read());
  }
}

//function determines if message is for arm, gripper, enables communications, request for gripper position
void read_msg_from_pc() {
  char inByte = Serial.read();

  if (enable == true) {
    if (inByte == '#') {//CMD for scara
      pass_to_scara();
    }
    else  if (inByte == '&') {//CMD for gripper
      read_gripper_msg(); 
    }
  }

  else {
    if (inByte == '&') {
      char inByte = Serial.read();
      if (inByte == 'E') {
        Serial.println("Enabled control of arm and gripper");
        enable = true;
        clear_serial_buffer();
        Serial.print("&S"); //Current gripper value 
        Serial.println(sensor - minreach);
      }
    }
  }
}

//main loop - checks for serial input 
void loop() {
  sensor = filtered_read();
  if (Serial.available() > 0) {
    delay(1);
    read_msg_from_pc();
  }
  if (Serial1.available() > 0) {
    delay(1);
    pass_from_scara();
  }
  delay(1);
}

/* References-
 *  
 *  Code used for implimentation of PID control:
 *  https://github.com/signalben/Versatile-Arduino-Network/blob/main/libraries/van_dev_pid/van_dev_pid.cpp
 *  
 *  Library used for adding second serial port:
 *  https://www.arduino.cc/reference/en/libraries/altsoftserial/
 */

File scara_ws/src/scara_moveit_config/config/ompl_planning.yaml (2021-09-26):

planner_configs:
  SBL:
    type: geometric::SBL
    range: 0.0  # Max motion added to tree. ==> maxDistance_ default: 0.0, if 0.0, set on setup()
  EST:
    type: geometric::EST
    range: 0.0  # Max motion added to tree. ==> maxDistance_ default: 0.0, if 0.0 setup()
    goal_bias: 0.05  # When close to goal select goal, with this probability. default: 0.05
  LBKPIECE:
    type: geometric::LBKPIECE
    range: 0.0  # Max motion added to tree. ==> maxDistance_ default: 0.0, if 0.0, set on setup()
    border_fraction: 0.9  # Fraction of time focused on boarder default: 0.9
    min_valid_path_fraction: 0.5  # Accept partially valid moves above fraction. default: 0.5
  BKPIECE:
    type: geometric::BKPIECE
    range: 0.0  # Max motion added to tree. ==> maxDistance_ default: 0.0, if 0.0, set on setup()
    border_fraction: 0.9  # Fraction of time focused on boarder default: 0.9
    failed_expansion_score_factor: 0.5  # When extending motion fails, scale score by factor. default: 0.5
    min_valid_path_fraction: 0.5  # Accept partially valid moves above fraction. default: 0.5
  KPIECE:
    type: geometric::KPIECE
    range: 0.0  # Max motion added to tree. ==> maxDistance_ default: 0.0, if 0.0, set on setup()
    goal_bias: 0.05  # When close to goal select goal, with this probability. default: 0.05
    border_fraction: 0.9  # Fraction of time focused on boarder default: 0.9 (0.0,1.]
    failed_expansion_score_factor: 0.5  # When extending motion fails, scale score by factor. default: 0.5
    min_valid_path_fraction: 0.5  # Accept partially valid moves above fraction. default: 0.5
  RRT:
    type: geometric::RRT
    range: 0.0  # Max motion added to tree. ==> maxDistance_ default: 0.0, if 0.0, set on setup()
    goal_bias: 0.05  # When close to goal select goal, with this probability? default: 0.05
  RRTConnect:
    type: geometric::RRTConnect
    range: 0.0  # Max motion added to tree. ==> maxDistance_ default: 0.0, if 0.0, set on setup()
  RRTstar:
    type: geometric::RRTstar
    range: 0.0  # Max motion added to tree. ==> maxDistance_ default: 0.0, if 0.0, set on setup()
    goal_bias: 0.05  # When close to goal select goal, with this probability? default: 0.05
    delay_collision_checking: 1  # Stop collision checking as soon as C-free parent found. default 1
  TRRT:
    type: geometric::TRRT
    range: 0.0  # Max motion added to tree. ==> maxDistance_ default: 0.0, if 0.0, set on setup()
    goal_bias: 0.05  # When close to goal select goal, with this probability? default: 0.05
    max_states_failed: 10  # when to start increasing temp. default: 10
    temp_change_factor: 2.0  # how much to increase or decrease temp. default: 2.0
    min_temperature: 10e-10  # lower limit of temp change. default: 10e-10
    init_temperature: 10e-6  # initial temperature. default: 10e-6
    frountier_threshold: 0.0  # dist new state to nearest neighbor to disqualify as frontier. default: 0.0 set in setup()
    frountierNodeRatio: 0.1  # 1/10, or 1 nonfrontier for every 10 frontier. default: 0.1
    k_constant: 0.0  # value used to normalize expresssion. default: 0.0 set in setup()
  PRM:
    type: geometric::PRM
    max_nearest_neighbors: 10  # use k nearest neighbors. default: 10
  PRMstar:
    type: geometric::PRMstar
  FMT:
    type: geometric::FMT
    num_samples: 1000  # number of states that the planner should sample. default: 1000
    radius_multiplier: 1.1  # multiplier used for the nearest neighbors search radius. default: 1.1
    nearest_k: 1  # use Knearest strategy. default: 1
    cache_cc: 1  # use collision checking cache. default: 1
    heuristics: 0  # activate cost to go heuristics. default: 0
    extended_fmt: 1  # activate the extended FMT*: adding new samples if planner does not finish successfully. default: 1
  BFMT:
    type: geometric::BFMT
    num_samples: 1000  # number of states that the planner should sample. default: 1000
    radius_multiplier: 1.0  # multiplier used for the nearest neighbors search radius. default: 1.0
    nearest_k: 1  # use the Knearest strategy. default: 1
    balanced: 0  # exploration strategy: balanced true expands one tree every iteration. False will select the tree with lowest maximum cost to go. default: 1
    optimality: 1  # termination strategy: optimality true finishes when the best possible path is found. Otherwise, the algorithm will finish when the first feasible path is found. default: 1
    heuristics: 1  # activates cost to go heuristics. default: 1
    cache_cc: 1  # use the collision checking cache. default: 1
    extended_fmt: 1  # Activates the extended FMT*: adding new samples if planner does not finish successfully. default: 1
  PDST:
    type: geometric::PDST
  STRIDE:
    type: geometric::STRIDE
    range: 0.0  # Max motion added to tree. ==> maxDistance_ default: 0.0, if 0.0, set on setup()
    goal_bias: 0.05  # When close to goal select goal, with this probability. default: 0.05
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

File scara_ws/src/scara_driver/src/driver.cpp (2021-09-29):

#include <ros/ros.h>
#include <serial/serial.h>
#include <std_msgs/String.h>
#include <std_msgs/Empty.h>
#include <std_msgs/Char.h>
#include <std_msgs/Float32.h>
#include "sensor_msgs/JointState.h"
#include "std_msgs/UInt16.h"
#include "math.h"
#include <string.h>    
#include <sstream>
#include <iostream>
#include <boost/algorithm/string.hpp>
#include <cstdlib>
#include <boost/lexical_cast.hpp>

//This node handles communication with the arm and gripper over the serial port

using namespace std;

//Template used to give std::to_string function (see references)
template <typename T>
std::string to_string(T val)
{
    std::stringstream stream;
    stream << val;
    return stream.str();
}

string use_port = "/dev/ttyUSB0";
int use_baud = 57600;
bool update = false;
float gripper_yaw_offset; //variable used to offset gripper rotation
serial::Serial ser;	  //declare serial port object

float gripper_scale = 18820; 			//gripper scale, offset used to convert from metres to gripper potentiomer readings
float gripper_offset = -51.791;
float target[4] = {0, 0, 0, 0}; 		//target joint values for manipulator
float current_joint_state[4] = {0, 0, 0, 0};	//current joint values, as reported by GRBL
float total_error = 0; 
float  low_lim[5] = {-270, -270, 0,  -180, 0  };//x,y,z,a upper and lower limits
float high_lim[5] = {   0,    0, 220,   180, 770};  

//sends strings recieved on the write topic directly
void write_callback(const std_msgs::String::ConstPtr& msg){

	cout << msg->data << endl;

	if (msg->data == "run"){
		update = true;
		cout << "Updating Jointstates from GRBL.." << endl;
	}

	if (msg->data == "stop"){
		update = false;
		cout << "Not updating Jointstates" << endl;
	}

	string to_write = msg->data  + "\r" + "\n";
	ser.write(to_write);
}


//callback triggered when target joint states change, passes target joint states to GRBL as G-CODE
void arm_cmd_cb(const sensor_msgs::JointState& cmd_arm)
{
	
	vector<string> names = cmd_arm.name; //strings of joint names with new targets
	
	string gcode = "#G1 F2200 "; //'#' prefix specifies command for GRBL, G1 F2200 specifies controlled motion and velocity 
	bool send_gcode = false;     //won't send G-CODE if a valid command cannot be interpreted
	
	string gripper_cmd = "&C";   //'&' prefix specifies command for gripper
	bool send_gripper_position = false; //won't send by default

	for (int i=0; i<names.size(); i++){ //for every joint with new target
		
		//if J2, XJ
		if (names[i] == "XJ"){ 
			     float joint_val = 57.2958*cmd_arm.position[i]; 			//convert to degrees
			     joint_val = roundf(joint_val * 1000) / 1000;			//allow 3 decimal places

			     if((joint_val <= high_lim[0])&&(joint_val >= low_lim[0])){		//if within limits
				     gcode += " X" + to_string(joint_val);			//construct G-CODE string
				     target[0] = joint_val;					//store as new joint target
				     send_gcode = true;						//send G-CODE later
				}
			      else{
				cout << "Limits exceeded:" <<  names[i] << joint_val << endl;	//don't send any thing if limits exceeded, report error
				send_gcode = false;
				break;
				}
		}
		
		//repeat same process for all other joints of manipulator (YJ, ZJ, AJ)

		//if J3, YJ
		else if (names[i] == "YJ"){
			     float joint_val = 57.2958*cmd_arm.position[i];
			     joint_val = roundf(joint_val * 1000) / 1000;

			     if((joint_val <= high_lim[1])&&(joint_val >= low_lim[1])){
				     gcode += " Y" + to_string(joint_val);
				     target[1] = joint_val;
				     send_gcode = true;
				}
			      else{
				cout << "Limits exceeded:" <<  names[i] << joint_val << endl;
				send_gcode = false;
				break;
				}
		}

		//if J1, ZJ
		else if (names[i] == "ZJ"){
			     float joint_val = 1000*cmd_arm.position[i];
			     joint_val = roundf(joint_val * 10) / 10;

			     if((joint_val <= high_lim[2])&&(joint_val >= low_lim[2])){
				     gcode += " Z" + to_string(joint_val);
				     target[2] = joint_val;
				     send_gcode = true;
				}
			      else{
				cout << "Limits exceeded:" <<  names[i] << joint_val << endl;
				send_gcode = false;
				break;
				}
		}

		//if J4, AJ
		else if (names[i] == "AJ"){
			     float joint_val = 57.2958*(cmd_arm.position[i] - gripper_yaw_offset);
			     joint_val = roundf(joint_val * 10) / 10;		//round to 1dp (0.1mm)

			     if((joint_val <= high_lim[3])&&(joint_val >= low_lim[3])){
				     gcode += " A" + to_string(joint_val);
				     target[3] = joint_val;
				     send_gcode = true;
				}
			      else{
				cout << "Limits exceeded:" <<  names[i] << joint_val << endl;
				send_gcode = false;
				break;
				}
		}

		//if gripper jaw, G0
		else if (names[i] == "G0"){
			    float joint_val = gripper_scale*cmd_arm.position[i] + gripper_offset; //if gripper target specified, apply scaling
			    joint_val = roundf(joint_val);					  //round to 1dp

			    if((joint_val <= high_lim[4])&&(joint_val >= low_lim[4])){
				    gripper_cmd += to_string(joint_val);
				    cout << "gripper_cmd:" <<  gripper_cmd << endl;
				    send_gripper_position = true;
				}
			      else{
				cout << "Limits exceeded:" <<  names[i] << joint_val << endl;
				send_gcode = false;
				break;
				}
		}

		//G1 not used as the gripper jaws are mirrored
		else if (names[i] == "G1"){
		}

		//catch case- Don't send any commands
		else {
		      cout << "Unknown joint name recieved:" <<  names[i] << endl;
		      send_gcode = false;
		      send_gripper_position = false;
		}
	}

    //if a valid GRBL command was constructed, write it to the serial port
    if(send_gcode == true){
	cout << gcode << endl;
	ser.write(gcode);
    ser.write("\r");
	}

    //if a valid gripper command was constructed, write it to the serial port
    else if(send_gripper_position == true){
	cout << gripper_cmd << endl;
	ser.write(gripper_cmd);
	ser.write("\r");
        ser.write("\n");
	}
}
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

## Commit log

2021-09-22 Solidworks designs for scara arm, gripper, realsense mount, endstops, controller
    [35t_98.5percent.SLDPRT, 35t_htd.SLDPRT, 70t_V1.SLDPRT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]
2021-09-27 bulk upload
    [alarm_codes_en_US.csv, build_option_codes_en_US.csv, config.h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]

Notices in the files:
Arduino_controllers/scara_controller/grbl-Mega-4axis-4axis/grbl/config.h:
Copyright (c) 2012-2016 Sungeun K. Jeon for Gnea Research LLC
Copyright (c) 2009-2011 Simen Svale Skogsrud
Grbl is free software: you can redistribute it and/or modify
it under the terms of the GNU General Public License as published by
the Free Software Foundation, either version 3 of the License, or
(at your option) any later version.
